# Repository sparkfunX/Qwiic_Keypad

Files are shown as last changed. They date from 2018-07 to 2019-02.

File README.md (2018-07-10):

SparkFun Qwiic KeyPad
========================================

SparkFun Qwiic Keypad

[*SparkX Qwiic Keypad (SPX-14836)*](https://www.sparkfun.com/products/14836)

Keypads are very handy input devices. And there are many great libraries written to interface to keypads! But who wants to tie up 7 GPIOs, have a handful of pull up resistors, and write firmware that scans the keys taking up valuable megahertz? Let’s make it easier! The Qwiic Keypad uses very simple I2C commands to read what button was pressed. It also implements a stack with time stamps for each key press so you don’t need to constantly poll the keypad. Qwiic Keypad even has a configurable I2C address so you can have multiple keypads on the same bus!

Qwiic Keypad is very low power and uses less than 4mA at 3.3V. There are jumpers on the board allowing the user to select between different I2C addresses as well as to remove the I2C pull up resistors if needed.

The Qwiic Keypad comes fully assembled and uses the simple [Qwiic interface](https://www.sparkfun.com/qwiic). No soldering, no voltage translation, no figuring out which pin is SDA or SCL, just plug and go!

Repository Contents
-------------------

* **/Examples** - A number of examples to show how to read buttons with time, change the I2C address and scan for I2C devices
* **/Firmware** - The core sketch that runs Qwiic Keypad
* **/Hardware** - Eagle design files (.brd, .sch)

License Information
-------------------

This product is _**open source**_! 

Please review the LICENSE.md file for license information. 

If you have any questions or concerns on licensing, please contact techsupport@sparkfun.com.

Please use, reuse, and modify these files as you see fit. Please maintain attribution to SparkFun Electronics and release any derivative under the same license.

Distributed as-is; no warranty is given.

- Your friends at SparkFun.

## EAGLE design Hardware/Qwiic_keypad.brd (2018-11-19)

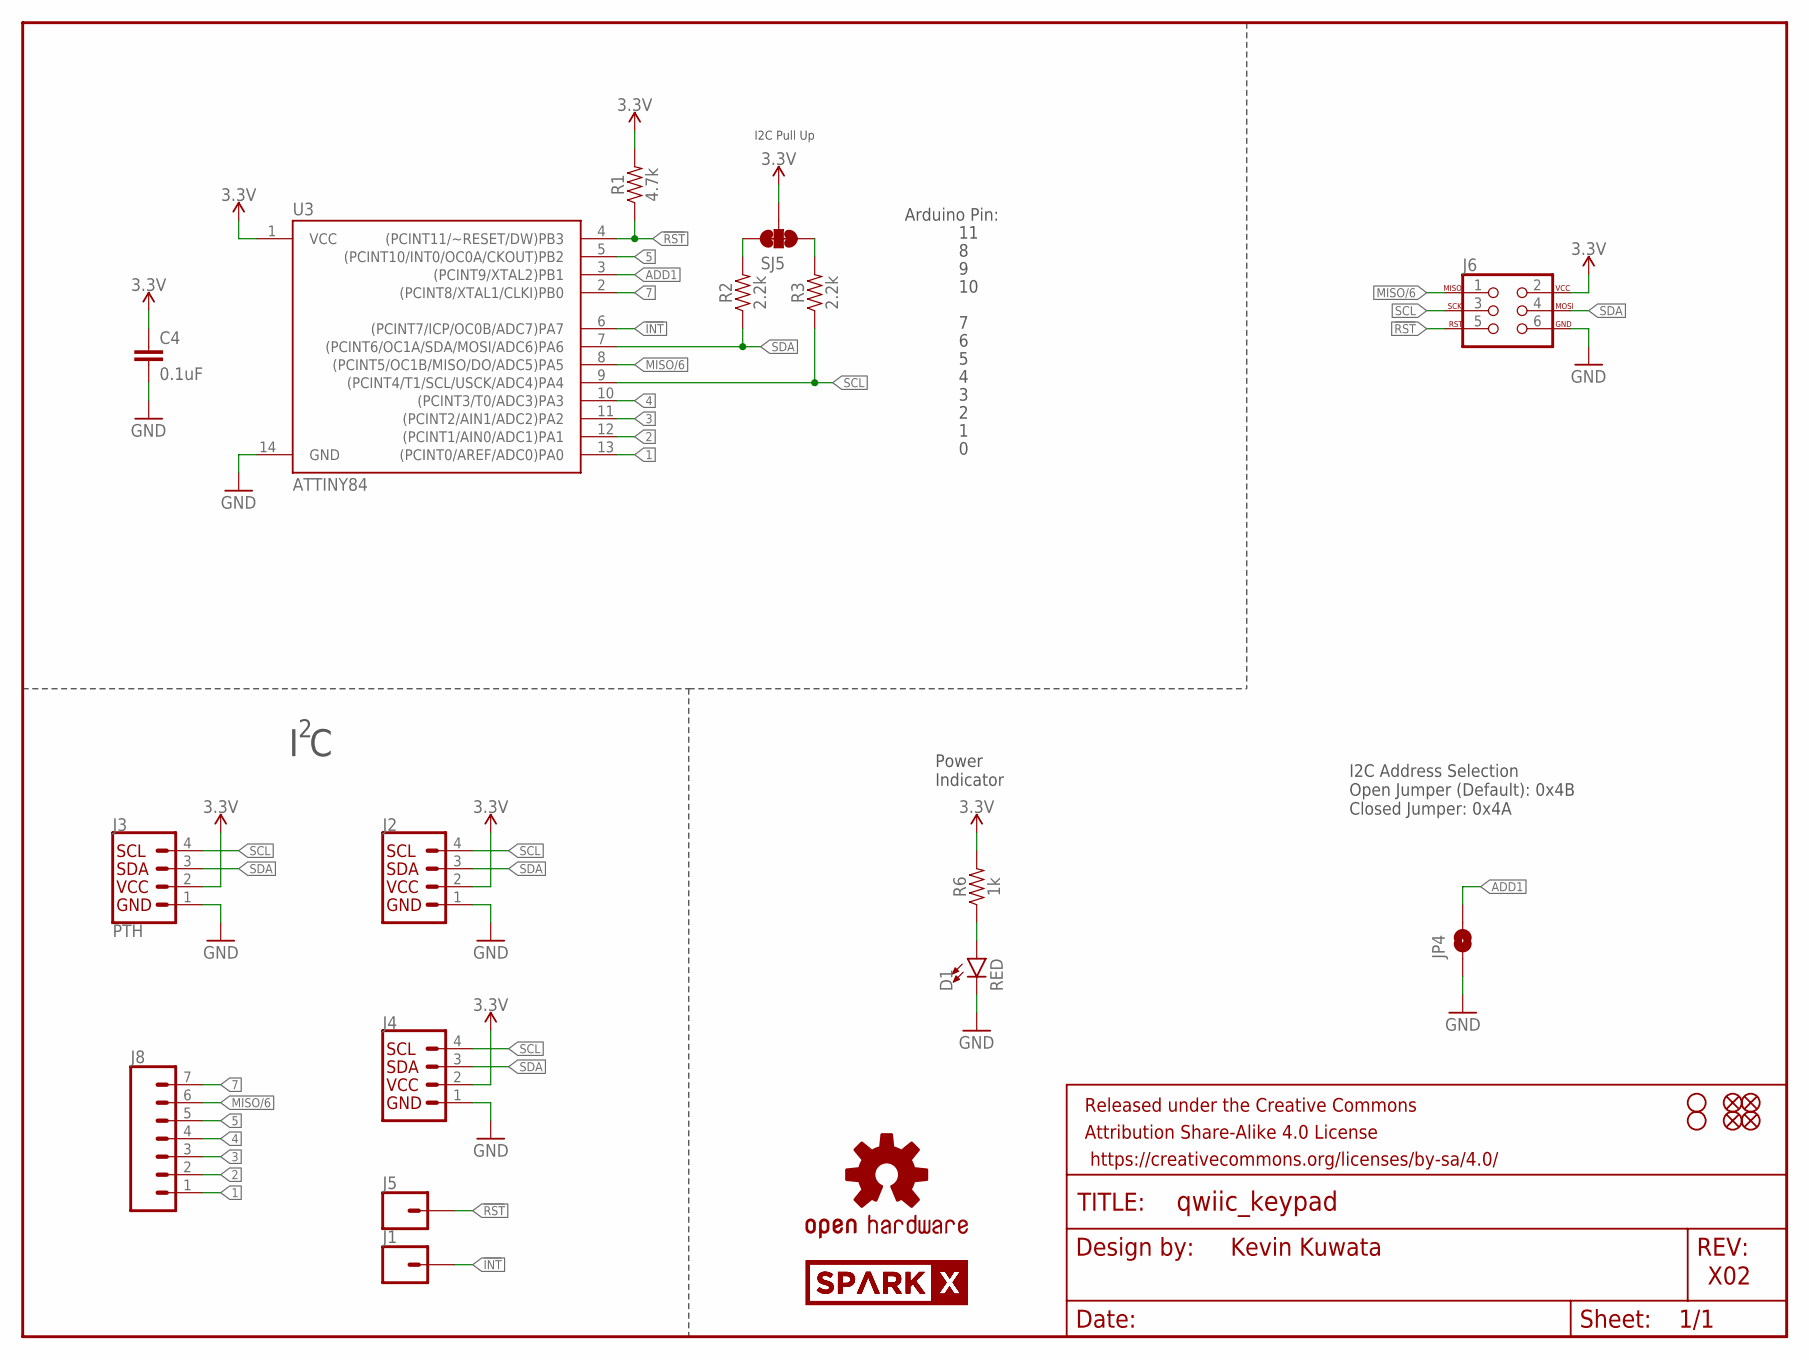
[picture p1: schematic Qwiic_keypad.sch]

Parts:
C4: 0.1uF; 0603
D1: RED; LED-0603
FRAME1: FRAME-LETTER; CREATIVE_COMMONS
H1, H2: STAND-OFF
J1, J5: CONN_01PTH_NO_SILK_YES_STOP; 1X01_NO_SILK
J2, J4: QWIIC_CONNECTORJS-1MM; 1X04_1MM_RA
J3: PTH; 1X04_NO_SILK
J6: AVR_SPI_PROG_3X2TESTPOINTS; 2X3_TEST_POINTS
J8: CONN_07NO_SILK; 1X07_NO_SILK
JP1, JP2, JP3, JP6: FIDUCIALUFIDUCIAL; MICRO-FIDUCIAL
JP4: JUMPER-SMT_2_NO_SILK; SMT-JUMPER_2_NO_SILK
LOGO1: OSHW-LOGOMINI; OSHW-LOGO-MINI
R1: 4.7k; 0603
R2, R3: 2.2k; 0603
R6: 1k; 0603
SJ5: JUMPER-SMT_3_2-NC_TRACE_SILK; SMT-JUMPER_3_2-NC_TRACE_SILK
U3: ATTINY84; SO14
U$1, U$2: SPARKX-LOGO3; SPARKX-SMALL

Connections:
1: J8.1, U3.13 ((PCINT0/AREF/ADC0)PA0)
2: J8.2, U3.12 ((PCINT1/AIN0/ADC1)PA1)
3: J8.3, U3.11 ((PCINT2/AIN1/ADC2)PA2)
3.3V: C4.1, J2.2, J3.2 (VCC), J4.2, J6.2, R1.2, R6.2, SJ5.2, U3.1 (VCC)
4: J8.4, U3.10 ((PCINT3/T0/ADC3)PA3)
5: J8.5, U3.5 ((PCINT10/INT0/OC0A/CKOUT)PB2)
7: J8.7, U3.2 ((PCINT8/XTAL1/CLKI)PB0)
!INT: J1.1, U3.6 ((PCINT7/ICP/OC0B/ADC7)PA7)
!RST: J5.1, J6.5, R1.1, U3.4 ((PCINT11/~RESET/DW)PB3)
ADD1: JP4.2, U3.3 ((PCINT9/XTAL2)PB1)
GND: C4.2, D1.C, J2.1, J3.1 (GND), J4.1, J6.6, JP4.1, U3.14 (GND)
MISO/6: J6.1, J8.6, U3.8 ((PCINT5/OC1B/MISO/DO/ADC5)PA5)
unnamed: D1.A, R6.1
unnamed: R2.2, SJ5.3
unnamed: R3.2, SJ5.1
SCL: J2.4, J3.4 (SCL), J4.4, J6.3, R3.1, U3.9 ((PCINT4/T1/SCL/USCK/ADC4)PA4)
SDA: J2.3, J3.3 (SDA), J4.3, J6.4, R2.1, U3.7 ((PCINT6/OC1A/SDA/MOSI/ADC6)PA6)

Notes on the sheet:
Kevin Kuwata
X02
I C
I2C Address Selection Open Jumper (Default): 0x4B Closed Jumper: 0x4A
Power Indicator
I2C Pull Up
Arduino Pin:

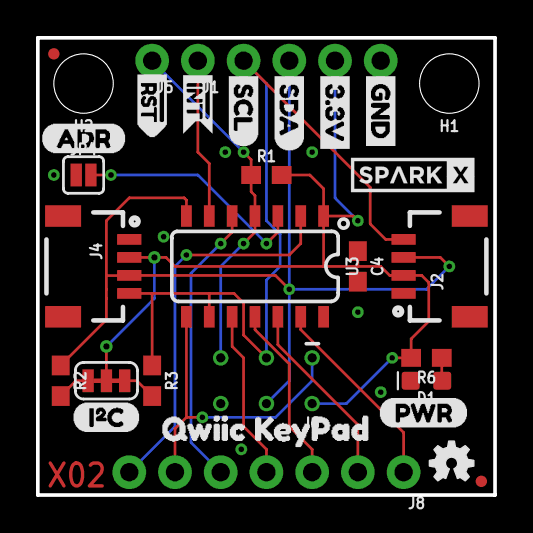
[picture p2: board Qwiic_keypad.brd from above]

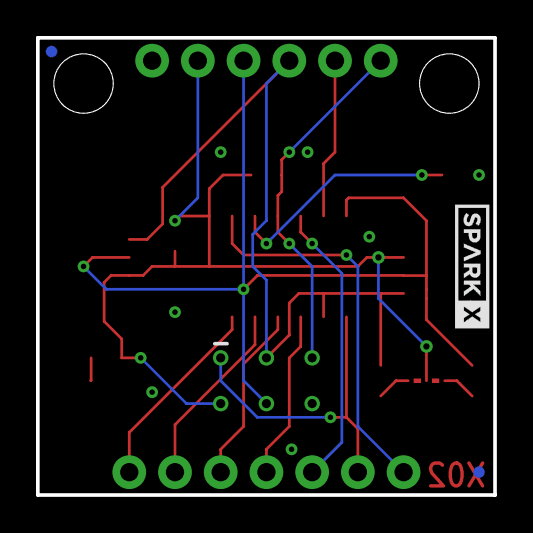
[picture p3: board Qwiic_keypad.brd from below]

Board: 2 copper layers, 25.4 x 25.4 mm, 36 parts (3 on the bottom side), 17 nets.

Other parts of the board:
U$3: 3.3V
U$4: GND
U$5: SDA
U$6: SCL
U$8: (PWR)
U$9: (I_SUPER2_C)
U$10: (ADR)
U$11: #RST>
U$12: #INT1
U$15: QWIIC_KEYPAD0

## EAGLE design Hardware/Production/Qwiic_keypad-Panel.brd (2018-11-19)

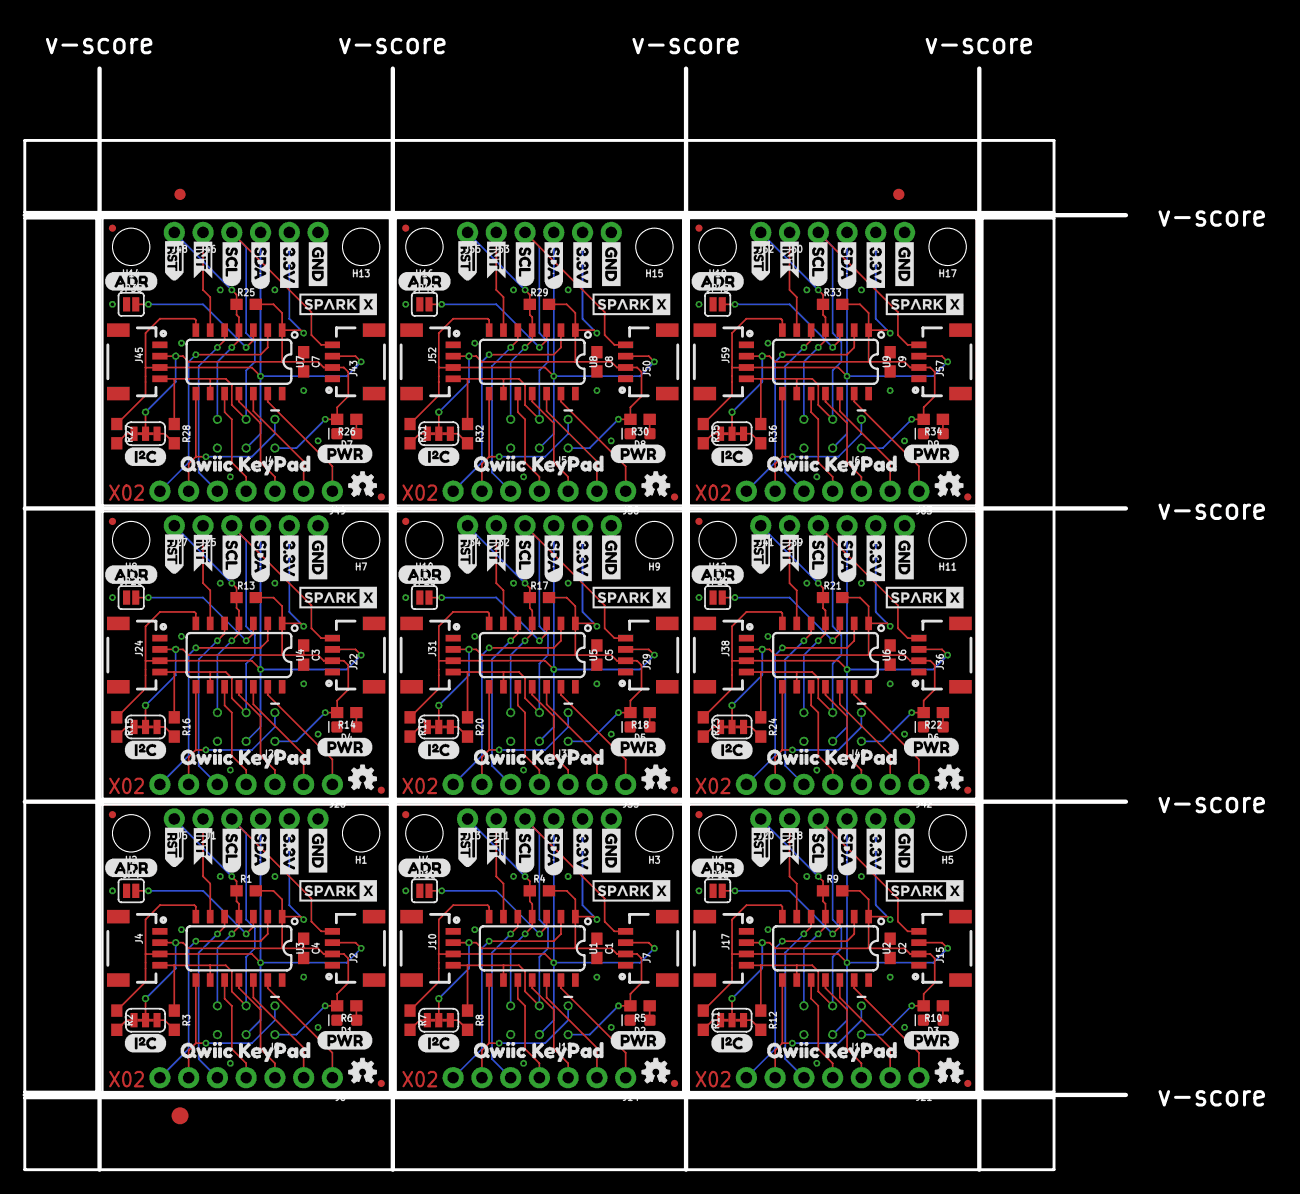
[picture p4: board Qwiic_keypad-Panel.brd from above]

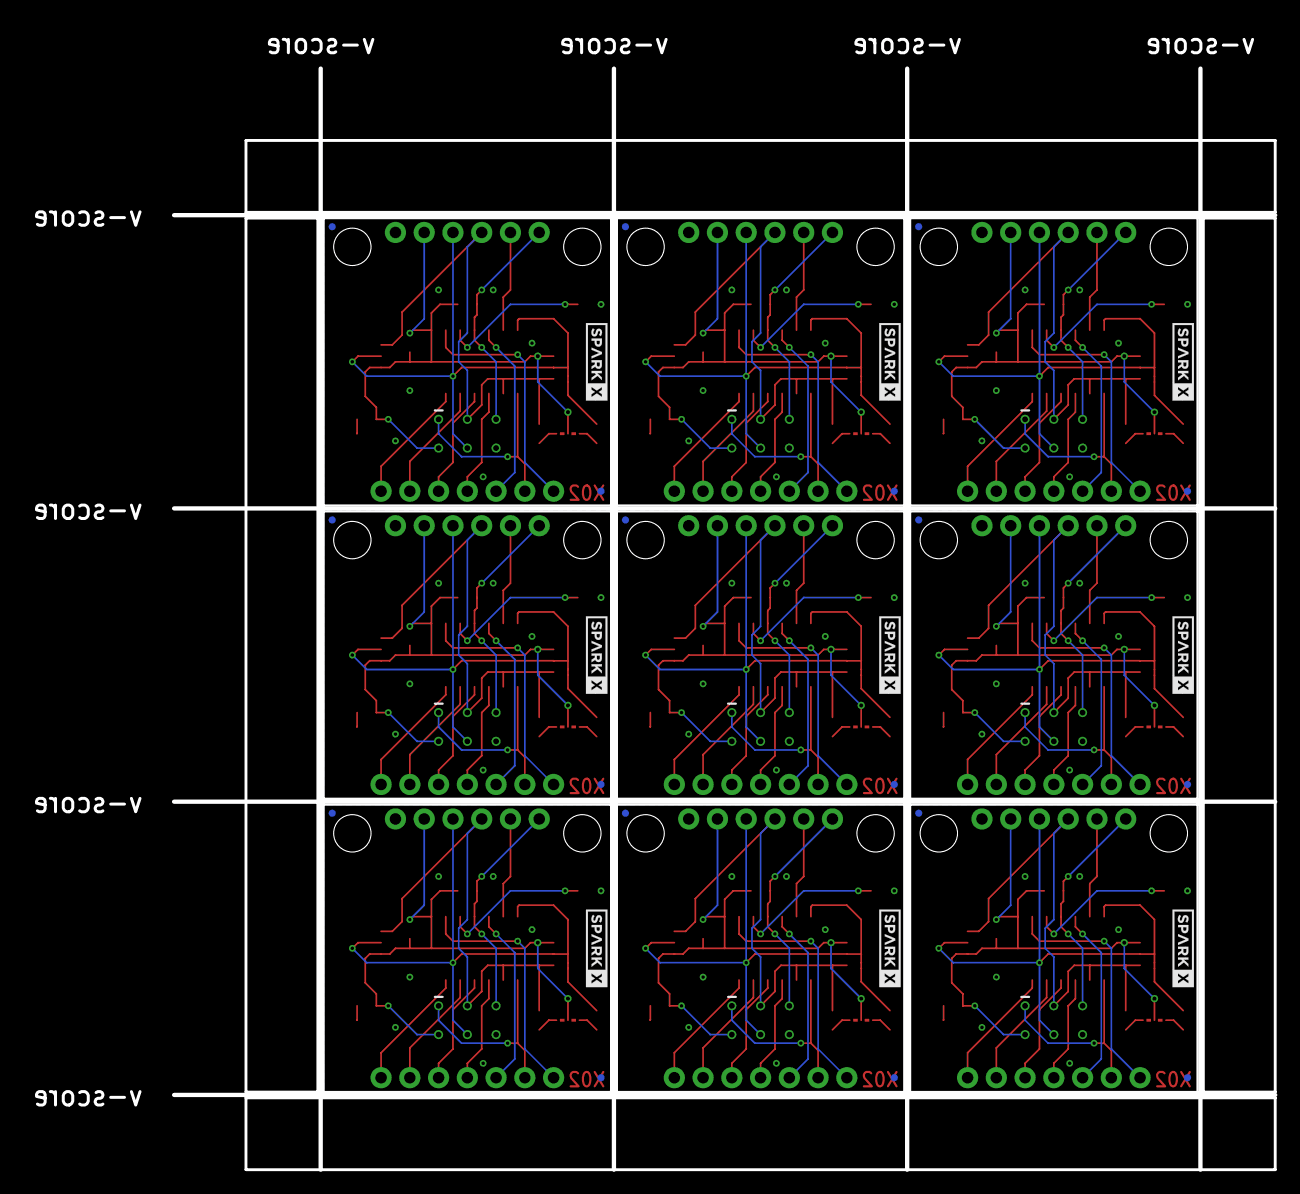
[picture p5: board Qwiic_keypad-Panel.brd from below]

Board: 2 copper layers, 97.3 x 97.3 mm, 318 parts (27 on the bottom side), 153 nets.

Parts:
C1, C2, C3, C4, C5, C6, C7, C8, C9: 0.1uF; 0603
D1, D2, D3, D4, D5, D6, D7, D8, D9: RED; LED-0603
E$1, E$2: FIDUCIAL-1X2
E$3: FIDUCIAL-1.5X3
H1, H2, H3, H4, H5, H6, H7, H8, H9, H10, H11, H12, H13, H14, H15, H16, H17, H18: STAND-OFF
J1, J5, J11, J13, J18, J20, J25, J27, J32, J34, J39, J41, J46, J48, J53, J55, J60, J62: 1X01_NO_SILK
J2, J4, J7, J10, J15, J17, J22, J24, J29, J31, J36, J38, J43, J45, J50, J52, J57, J59: 1X04_1MM_RA
J3, J9, J16, J23, J30, J37, J44, J51, J58: PTH; 1X04_NO_SILK
J6, J12, J19, J26, J33, J40, J47, J54, J61: AVR_SPI_PROG_3X2TESTPOINTS; 2X3_TEST_POINTS
J8, J14, J21, J28, J35, J42, J49, J56, J63: 1X07_NO_SILK
JP1, JP2, JP3, JP5, JP6, JP7, JP8, JP9, JP11, JP12, JP13, JP14, JP16, JP17, JP18, JP19, JP21, JP22, JP23, JP24, JP26, JP27, JP28, JP29, JP31, JP32, JP33, JP34, JP36, JP37, JP38, JP39, JP41, JP42, JP43, JP44: FIDUCIALUFIDUCIAL; MICRO-FIDUCIAL
JP4, JP10, JP15, JP20, JP25, JP30, JP35, JP40, JP45: SMT-JUMPER_2_NO_SILK
LOGO1, LOGO2, LOGO3, LOGO4, LOGO5, LOGO6, LOGO7, LOGO8, LOGO9: OSHW-LOGOMINI; OSHW-LOGO-MINI
R1, R4, R9, R13, R17, R21, R25, R29, R33: 4.7k; 0603
R2, R3, R7, R8, R11, R12, R15, R16, R19, R20, R23, R24, R27, R28, R31, R32, R35, R36: 2.2k; 0603
R5, R6, R10, R14, R18, R22, R26, R30, R34: 1k; 0603
SJ1, SJ2, SJ3, SJ4, SJ5, SJ6, SJ7, SJ8, SJ9: SMT-JUMPER_3_2-NC_TRACE_SILK
U1, U2, U3, U4, U5, U6, U7, U8, U9: ATTINY84; SO14
U$1, U$2, U$7, U$13, U$25, U$26, U$37, U$38, U$49, U$50, U$61, U$62, U$73, U$74, U$85, U$86, U$97, U$98: SPARKX-LOGO3; SPARKX-SMALL
U$3, U$14, U$27, U$39, U$51, U$63, U$75, U$87, U$99: 3.3V
U$4, U$16, U$28, U$40, U$52, U$64, U$76, U$88, U$100: GND
U$5, U$17, U$29, U$41, U$53, U$65, U$77, U$89, U$101: SDA
U$6, U$18, U$30, U$42, U$54, U$66, U$78, U$90, U$102: SCL
U$8, U$19, U$31, U$43, U$55, U$67, U$79, U$91, U$103: (PWR)
U$9, U$20, U$32, U$44, U$56, U$68, U$80, U$92, U$104: (I_SUPER2_C)
U$10, U$21, U$33, U$45, U$57, U$69, U$81, U$93, U$105: (ADR)
U$11, U$22, U$34, U$46, U$58, U$70, U$82, U$94, U$106: #RST>
U$12, U$24, U$36, U$48, U$60, U$72, U$84, U$96, U$108: #INT1
U$15, U$23, U$35, U$47, U$59, U$71, U$83, U$95, U$107: QWIIC_KEYPAD0

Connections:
1: J8.1, U3.13
2: J8.2, U3.12
3: J8.3, U3.11
3.3V: C4.1, J2.2, J3.2, J4.2, J6.2, R1.2, R6.2, SJ5.2, U3.1
3.3V1: C1.1, J7.2, J9.2, J10.2, J12.2, R4.2, R5.2, SJ1.2, U1.1
3.3V2: C2.1, J15.2, J16.2, J17.2, J19.2, R9.2, R10.2, SJ2.2, U2.1
3.3V3: C3.1, J22.2, J23.2, J24.2, J26.2, R13.2, R14.2, SJ3.2, U4.1
3.3V4: C5.1, J29.2, J30.2, J31.2, J33.2, R17.2, R18.2, SJ4.2, U5.1
3.3V5: C6.1, J36.2, J37.2, J38.2, J40.2, R21.2, R22.2, SJ6.2, U6.1
3.3V6: C7.1, J43.2, J44.2, J45.2, J47.2, R25.2, R26.2, SJ7.2, U7.1
3.3V7: C8.1, J50.2, J51.2, J52.2, J54.2, R29.2, R30.2, SJ8.2, U8.1
3.3V8: C9.1, J57.2, J58.2, J59.2, J61.2, R33.2, R34.2, SJ9.2, U9.1
4: J8.4, U3.10
5: J8.5, U3.5
6: J14.4, U1.10
7: J8.7, U3.2
8: J14.3, U1.11
9: J14.2, U1.12
10: J14.1, U1.13
11: J14.7, U1.2
12: J14.5, U1.5
13: J21.4, U2.10
14: J21.3, U2.11
15: J21.2, U2.12
16: J21.1, U2.13
17: J21.7, U2.2
18: J21.5, U2.5
19: J28.4, U4.10
20: J28.3, U4.11
21: J28.2, U4.12
22: J28.1, U4.13
23: J28.7, U4.2
24: J28.5, U4.5
25: J35.4, U5.10
26: J35.3, U5.11
27: J35.2, U5.12
28: J35.1, U5.13
29: J35.7, U5.2
30: J35.5, U5.5
31: J42.4, U6.10
32: J42.3, U6.11
33: J42.2, U6.12
34: J42.1, U6.13
35: J42.7, U6.2
36: J42.5, U6.5
37: J49.4, U7.10
38: J49.3, U7.11
39: J49.2, U7.12
40: J49.1, U7.13
41: J49.7, U7.2
42: J49.5, U7.5
43: J56.4, U8.10
44: J56.3, U8.11
45: J56.2, U8.12
46: J56.1, U8.13
47: J56.7, U8.2
48: J56.5, U8.5
49: J63.4, U9.10
50: J63.3, U9.11
51: J63.2, U9.12
52: J63.1, U9.13
53: J63.7, U9.2
54: J63.5, U9.5
!INT: J1.1, U3.6
!INT1: J11.1, U1.6
!INT2: J18.1, U2.6
!INT3: J25.1, U4.6
!INT4: J32.1, U5.6
!INT5: J39.1, U6.6
!INT6: J46.1, U7.6
!INT7: J53.1, U8.6
!INT8: J60.1, U9.6
!RST: J5.1, J6.5, R1.1, U3.4
!RST1: J12.5, J13.1, R4.1, U1.4
!RST2: J19.5, J20.1, R9.1, U2.4
!RST3: J26.5, J27.1, R13.1, U4.4
!RST4: J33.5, J34.1, R17.1, U5.4
!RST5: J40.5, J41.1, R21.1, U6.4
!RST6: J47.5, J48.1, R25.1, U7.4
!RST7: J54.5, J55.1, R29.1, U8.4
!RST8: J61.5, J62.1, R33.1, U9.4
ADD1: JP4.2, U3.3
ADD2: JP10.2, U1.3
ADD3: JP15.2, U2.3
ADD4: JP20.2, U4.3
ADD5: JP25.2, U5.3
ADD6: JP30.2, U6.3
ADD7: JP35.2, U7.3
ADD8: JP40.2, U8.3
ADD9: JP45.2, U9.3
GND: C4.2, D1.C, J2.1, J3.1, J4.1, J6.6, JP4.1, U3.14
GND1: C1.2, D2.C, J7.1, J9.1, J10.1, J12.6, JP10.1, U1.14
GND2: C2.2, D3.C, J15.1, J16.1, J17.1, J19.6, JP15.1, U2.14
GND3: C3.2, D4.C, J22.1, J23.1, J24.1, J26.6, JP20.1, U4.14
GND4: C5.2, D5.C, J29.1, J30.1, J31.1, J33.6, JP25.1, U5.14
GND5: C6.2, D6.C, J36.1, J37.1, J38.1, J40.6, JP30.1, U6.14
GND6: C7.2, D7.C, J43.1, J44.1, J45.1, J47.6, JP35.1, U7.14
GND7: C8.2, D8.C, J50.1, J51.1, J52.1, J54.6, JP40.1, U8.14
GND8: C9.2, D9.C, J57.1, J58.1, J59.1, J61.6, JP45.1, U9.14
MISO/1: J12.1, J14.6, U1.8
MISO/2: J19.1, J21.6, U2.8
MISO/3: J26.1, J28.6, U4.8
MISO/4: J33.1, J35.6, U5.8
MISO/5: J40.1, J42.6, U6.8
MISO/6: J6.1, J8.6, U3.8
MISO/7: J47.1, J49.6, U7.8
MISO/8: J54.1, J56.6, U8.8
MISO/9: J61.1, J63.6, U9.8
unnamed: D1.A, R6.1
unnamed: R2.2, SJ5.3
unnamed: R3.2, SJ5.1
unnamed: D2.A, R5.1
unnamed: R7.2, SJ1.3
unnamed: R8.2, SJ1.1
unnamed: D3.A, R10.1
unnamed: R11.2, SJ2.3
unnamed: R12.2, SJ2.1
unnamed: D4.A, R14.1
unnamed: R15.2, SJ3.3
unnamed: R16.2, SJ3.1
unnamed: D5.A, R18.1
unnamed: R19.2, SJ4.3
unnamed: R20.2, SJ4.1
unnamed: D6.A, R22.1
unnamed: R23.2, SJ6.3
unnamed: R24.2, SJ6.1
unnamed: D7.A, R26.1
unnamed: R27.2, SJ7.3
unnamed: R28.2, SJ7.1
unnamed: D8.A, R30.1
unnamed: R31.2, SJ8.3
unnamed: R32.2, SJ8.1
unnamed: D9.A, R34.1
unnamed: R35.2, SJ9.3
unnamed: R36.2, SJ9.1
SCL: J2.4, J3.4, J4.4, J6.3, R3.1, U3.9
SCL1: J7.4, J9.4, J10.4, J12.3, R8.1, U1.9
SCL2: J15.4, J16.4, J17.4, J19.3, R12.1, U2.9
SCL3: J22.4, J23.4, J24.4, J26.3, R16.1, U4.9
SCL4: J29.4, J30.4, J31.4, J33.3, R20.1, U5.9
SCL5: J36.4, J37.4, J38.4, J40.3, R24.1, U6.9
SCL6: J43.4, J44.4, J45.4, J47.3, R28.1, U7.9
SCL7: J50.4, J51.4, J52.4, J54.3, R32.1, U8.9
SCL8: J57.4, J58.4, J59.4, J61.3, R36.1, U9.9
SDA: J2.3, J3.3, J4.3, J6.4, R2.1, U3.7
SDA1: J7.3, J9.3, J10.3, J12.4, R7.1, U1.7
SDA2: J15.3, J16.3, J17.3, J19.4, R11.1, U2.7
SDA3: J22.3, J23.3, J24.3, J26.4, R15.1, U4.7
SDA4: J29.3, J30.3, J31.3, J33.4, R19.1, U5.7
SDA5: J36.3, J37.3, J38.3, J40.4, R23.1, U6.7
SDA6: J43.3, J44.3, J45.3, J47.4, R27.1, U7.7
SDA7: J50.3, J51.3, J52.3, J54.4, R31.1, U8.7
SDA8: J57.3, J58.3, J59.3, J61.4, R35.1, U9.7

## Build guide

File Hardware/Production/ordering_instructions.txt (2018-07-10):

panel size, 91x91mm
PCB thickness, 1.6mm
number of layers, 2
soldermask color, Black
silkscreen color, White
oz copper, 1oz
finish, HASL lead free
stencils, top
pcs per panel, 9

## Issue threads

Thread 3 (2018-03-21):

Add mounting holes, remove header holes

nseidle, 2018-03-21:
It won't help much but add 1" spaced Qwiic mounting holes.

If it allows the board to be smaller we can removed the unconnected header pins as well.

Closed 2018-07-10.

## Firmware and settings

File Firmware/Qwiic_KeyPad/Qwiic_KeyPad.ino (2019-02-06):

/*
  An I2C based KeyPad
  By: Nathan Seidle
  SparkFun Electronics
  Date: January 21st, 2018
  License: This code is public domain but you buy me a beer if you use this and we meet someday (Beerware license).

  Qwiic KeyPad is an I2C based key pad that records any button presses to a stack. If quered by the 
  master KeyPad will respond with the oldest button pressed along with the time since it was pressed.

  For example, if you Wire.request(75, 3) you'll get three bytes from KeyPad and they might read:
  byte 0: 0x34 - ASCII '4', button four was pressed
  byte 1: 0x01 - The MSB of a 16-bit unsigned integer
  byte 2: 0x5A - The LSB of a 16-bit unsigned integer

  0x015A = 346 so button 4 was pressed 346 milliseconds ago

  Feel like supporting our work? Buy a board from SparkFun!
  https://www.sparkfun.com/products/14641

  To install support for ATtiny84 in Arduino IDE: https://github.com/SpenceKonde/ATTinyCore/blob/master/Installation.md
  This core is installed from the Board Manager menu
  This core has built in support for I2C S/M and serial
  If you have Dave Mellis' ATtiny installed you may need to remove it from \Users\xx\AppData\Local\Arduino15\Packages

  To support 400kHz I2C communication reliably ATtiny84 needs to run at 8MHz. This requires user to
  click on 'Burn Bootloader' before code is loaded.

*/

#include <Wire.h>

#include <EEPROM.h>

#include <avr/sleep.h> //Needed for sleep_mode
#include <avr/power.h> //Needed for powering down perihperals such as the ADC/TWI and Timers

#define LOCATION_I2C_ADDRESS 0x01 //Location in EEPROM where the I2C address is stored
#define I2C_ADDRESS_DEFAULT 75
#define I2C_ADDRESS_JUMPER 74

#define COMMAND_CHANGE_ADDRESS 0xC7

//Variables used in the I2C interrupt so we use volatile
volatile byte setting_i2c_address = I2C_ADDRESS_DEFAULT; //The 7-bit I2C address of this KeyPad

byte responseBuffer[3]; //Used to pass data back to master
volatile byte responseSize = 1; //Defines how many bytes of relevant data is contained in the responseBuffer

//This struc keeps a record of all the button presses
#define BUTTON_STACK_SIZE 15
struct {
  byte button; //Which button was pressed?
  unsigned long buttonTime; //When?
} buttonEvents[BUTTON_STACK_SIZE];
volatile byte newestPress = 0;
volatile byte oldestPress = 0;

const byte addr = 9; //Addr jumper
const byte interruptPin = 7; //Pin goes low when a button event is available

#include <Keypad.h>   // by Mark Stanley and Alexander Brevig 
const byte ROWS = 4;
const byte COLS = 3;
char keys[ROWS][COLS] = {
  {'6', '4', '5'},
  {'9', '7', '8'},
  {'#', '*', '0'},
  {'3', '1', '2'}
};

//Pin X on keypad is connected to Y:
//KeyPad               7, 6, 4, 2
byte rowPins[ROWS] = {10, 5, 3, 1};
//Keypad              5, 3, 1
byte colPins[COLS] = {8, 2, 0};
Keypad keypad = Keypad( makeKeymap(keys), rowPins, colPins, ROWS, COLS );

void setup(void)
{
  pinMode(addr, INPUT_PULLUP);
  pinMode(interruptPin, OUTPUT); //Goes low when a button event is on the stack

  //Disable ADC
  ADCSRA = 0;
  
  //Disble Brown-Out Detect
  MCUCR = bit (BODS) | bit (BODSE);
  MCUCR = bit (BODS);

  //Power down various bits of hardware to lower power usage
  //set_sleep_mode(SLEEP_MODE_PWR_DOWN);
  set_sleep_mode(SLEEP_MODE_IDLE);
  sleep_enable();

  readSystemSettings(); //Load all system settings from EEPROM

  startI2C(); //Determine the I2C address we should be using and begin listening on I2C bus
}

void loop(void)
{
  //Check for new key presses
  char key = keypad.getKey();
  if (key) {
    buttonEvents[newestPress].button = key;
    buttonEvents[newestPress].buttonTime = millis();
    if (newestPress++ == BUTTON_STACK_SIZE) newestPress = 0; //Wrap variable
  }

  //Set interrupt pin as needed
  if(newestPress != oldestPress)
    digitalWrite(interruptPin, LOW); //We have events on the stack!
  else
    digitalWrite(interruptPin, HIGH); //No button events to report

  sleep_mode(); //Stop everything and go to sleep. Wake up if I2C event occurs.
}

//When KeyPad receives data bytes, this function is called as an interrupt
//The only valid command we can receive from the master is the change I2C adddress command
void receiveEvent(int numberOfBytesReceived)
{
  while (Wire.available())
  {
    //Record bytes to local array
    byte incoming = Wire.read();

    if (incoming == COMMAND_CHANGE_ADDRESS) //Set new I2C address
    {
      if (Wire.available())
      {
        setting_i2c_address = Wire.read();

        //Error check
        if (setting_i2c_address < 0x08 || setting_i2c_address > 0x77)
          continue; //Command failed. This address is out of bounds.

        EEPROM.write(LOCATION_I2C_ADDRESS, setting_i2c_address);

        //Our I2C address may have changed because of user's command
        startI2C(); //Determine the I2C address we should be using and begin listening on I2C bus
      }
    }
  }
}

//Send back a number of bytes via an array, max 32 bytes
//When KeyPad gets a request for data from the user, this function is called as an interrupt
//The interrupt will respond with different types of data depending on what response state we are in
//The user sets the response type based on bytes sent to KeyPad
void requestEvent()
{
  loadNextPressToArray();

  //Send response buffer
  for (byte x = 0 ; x < responseSize ; x++)
    Wire.write(responseBuffer[x]);
}

//Take the FIFO button press off the stack and load it into the transmit array
void loadNextPressToArray()
{
  if (oldestPress != newestPress)
  {
    responseBuffer[0] = buttonEvents[oldestPress].button;

    unsigned long timeSincePressed = millis() - buttonEvents[oldestPress].buttonTime;

    responseBuffer[1] = timeSincePressed >> 8; //MSB
    responseBuffer[2] = timeSincePressed; //LSB
    if (oldestPress++ == BUTTON_STACK_SIZE) oldestPress = 0;
  }
  else
  {
    //No new button presses. Respond with a blank record
    responseBuffer[0] = 0; //No button pressed
    responseBuffer[1] = 0;
    responseBuffer[2] = 0;
  }

  responseSize = 3;
}

//Reads the current system settings from EEPROM
//If anything looks weird, reset setting to default value
void readSystemSettings(void)
{
  //Read what I2C address we should use
  setting_i2c_address = EEPROM.read(LOCATION_I2C_ADDRESS);
  if (setting_i2c_address == 255)
  {
    setting_i2c_address = I2C_ADDRESS_DEFAULT; //By default, we listen for I2C_ADDRESS_DEFAULT
    EEPROM.write(LOCATION_I2C_ADDRESS, setting_i2c_address);
  }
}

//Begin listening on I2C bus as I2C slave using the global variable setting_i2c_address
void startI2C()
{
  Wire.end(); //Before we can change addresses we need to stop
  
  if (digitalRead(addr) == HIGH) //Default is HIGH, the jumper is open
    Wire.begin(setting_i2c_address); //Start I2C and answer calls using address from EEPROM
  else
    Wire.begin(I2C_ADDRESS_JUMPER); //Force address to I2C_ADDRESS_JUMPER if user has closed the solder jumper

  //The connections to the interrupts are severed when a Wire.begin occurs. So re-declare them.
  Wire.onReceive(receiveEvent);
  Wire.onRequest(requestEvent);
}

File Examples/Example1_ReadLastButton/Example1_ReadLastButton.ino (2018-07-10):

/*
  An I2C based KeyPad
  By: Nathan Seidle
  SparkFun Electronics
  Date: January 21st, 2018
  License: This code is public domain but you buy me a beer if you use this and we meet someday (Beerware license).

  Feel like supporting our work? Buy a board from SparkFun!
  https://www.sparkfun.com/products/14641

  This example prints which button was pressed. Press * for space and # for new line.
  
  Qwiic KeyPad records any button presses to a stack. If quered by the master KeyPad will
  respond with the oldest button pressed along with the time since it was pressed.
*/

#include <Wire.h>

byte keypadAddress = 75; //75 (0x4B) is default, 74 if jumper is closed

void setup(void)
{
  Wire.begin();
  
  Serial.begin(9600);
  Serial.println("Read Qwiic KeyPad Example");
  Serial.println("Press a button: * to do a space. # to go to next line.");
}

void loop(void)
{
  char button = readKeyPad();

  if(button == -1)
  {
    Serial.println("No keypad detected");
    delay(1000);
  }
  else if(button != 0)
  {
    if(button == '#') Serial.println();
    else if(button == '*') Serial.print(" ");
    else Serial.print(button);
  }

  //Do something else. Don't call readKeyPad a ton otherwise you'll tie up the I2C bus
  delay(25); //25 is good, more is better
}

//Get the latest button
char readKeyPad()
{
  Wire.requestFrom((uint8_t)keypadAddress, (uint8_t)1);
  return(Wire.read());
}

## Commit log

2018-02-26 starting new route
    [Qwiic_keypad.brd]
2018-02-26 fixing folder structure to conform to standard
    [Qwiic_keypad.brd, Qwiic_keypad.sch]
2018-02-26 second layout complete
    [Qwiic_keypad.brd]
2018-02-26 changed header from 7 pin to 9 pin to accomidate extra pin on the keypad itself
    [Qwiic_keypad.brd, Qwiic_keypad.sch]
2018-03-21 Adding production ready firmware. Adding examples.
    [Qwiic_keypad-Panel.GBL, Qwiic_keypad-Panel.GBO, Qwiic_keypad-Panel.GBS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]
2018-03-21 Cleaning up repo.
    [Qwiic_keypad-Panel.GBL, Qwiic_keypad-Panel.GBO, Qwiic_keypad-Panel.GBS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]
2018-07-10 v2 update
    [Qwiic_keypad-Panel.GBL, Qwiic_keypad-Panel.GBO, Qwiic_keypad-Panel.GBS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]
2018-11-19 update with latest eagle info
    opened files in eagle 9.2.1
    [Qwiic_keypad.brd, Qwiic_keypad.sch]
2018-11-19 remove wire stub
    [Qwiic_keypad.brd]
2018-11-19 update panel and cam files
    update to normally closed i2c jumper
    [Qwiic_keypad-Panel.brd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]

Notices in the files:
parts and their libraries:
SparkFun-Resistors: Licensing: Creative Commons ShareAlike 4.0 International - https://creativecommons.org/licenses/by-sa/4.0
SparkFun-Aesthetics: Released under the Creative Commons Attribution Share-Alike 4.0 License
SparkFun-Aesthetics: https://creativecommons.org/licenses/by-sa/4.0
